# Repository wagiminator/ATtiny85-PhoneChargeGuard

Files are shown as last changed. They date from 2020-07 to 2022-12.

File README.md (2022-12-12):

# USB Phone Charge Guard
The ATtiny45/85 USB Phone Charge Guard controls and monitors the charging of phones and other devices. Voltage, current, power and energy are constantly measured via the INA219 and compared with the user limit values. It cuts off the power supply via a MOSFET when a condition selected by the user is reached. This allows the state of charge of the phone's Li-Ion battery to be controlled, thereby extending its service life. The user settings are saved in the EEPROM.

- Project Video (YouTube): https://youtu.be/9DHBoqHImcM
- Design Files (EasyEDA): https://easyeda.com/wagiminator/attiny85-phone-charge-guard

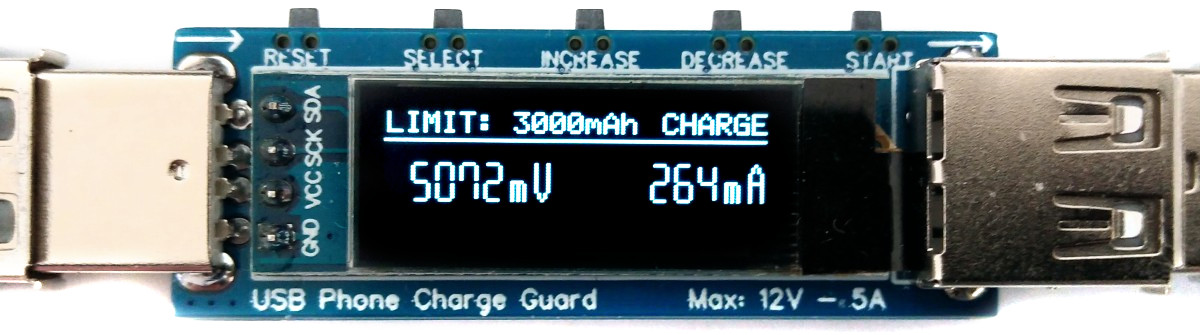
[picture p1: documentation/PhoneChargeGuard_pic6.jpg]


# Hardware
## USB Connectors
The device is equipped with a USB-A plug for the input and a USB-A socket for the output, so that it can be plugged between the power supply and the phone (or other consumers). D+ and D- are passed through so that the phone can negotiate the charging protocol.

## Voltage and Current Measurement
An [INA219](https://www.ti.com/lit/ds/symlink/ina219.pdf) is used to measure voltage and current. The INA219 is a current shunt and power monitor with an I²C-compatible interface. The device monitors both shunt voltage drop and bus supply voltage, with programmable conversion times and filtering. A programmable calibration value, combined with an internal multiplier, enables direct readouts of current in amperes. The selected shunt resistance of 8mΩ enables both a very small influence on the circuit and a measurement with a resolution of 1mA. For an accurate measurement, a shunt resistor with a low tolerance (1% or better) should be selected.

## Voltage Regulator
The device is supplied with 3.3V via an [HT7333](http://www.angeladvance.com/HT73xx.pdf) LDO voltage regulator, which taps the input voltage of up to 12V from the USB bus power.

## MOSFET
The connection between the power supply and the phone is switched on and off via an [AS3621](https://datasheet.lcsc.com/szlcsc/1809211432_AnBon-AS3621_C232288.pdf) P-channel MOSFET. Despite its small size, it can switch up to 30V with 6A continuously. Its internal on-resistance is only about 20 milliohms.

## User Interface
The user interface utilizes five buttons and an [SSD1306 128x32 pixels OLED display](http://aliexpress.com/wholesale?SearchText=128+32+0.91+oled). An [ATtiny45/85](https://ww1.microchip.com/downloads/en/DeviceDoc/Atmel-2586-AVR-8-bit-Microcontroller-ATtiny25-ATtiny45-ATtiny85_Datasheet.pdf) microcontroller handles the user interface, the control of the power connection and the calculation and display of the measured values.

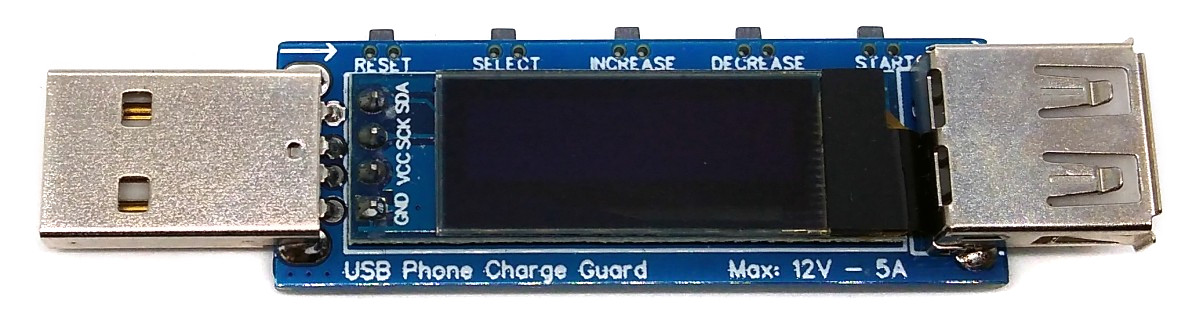
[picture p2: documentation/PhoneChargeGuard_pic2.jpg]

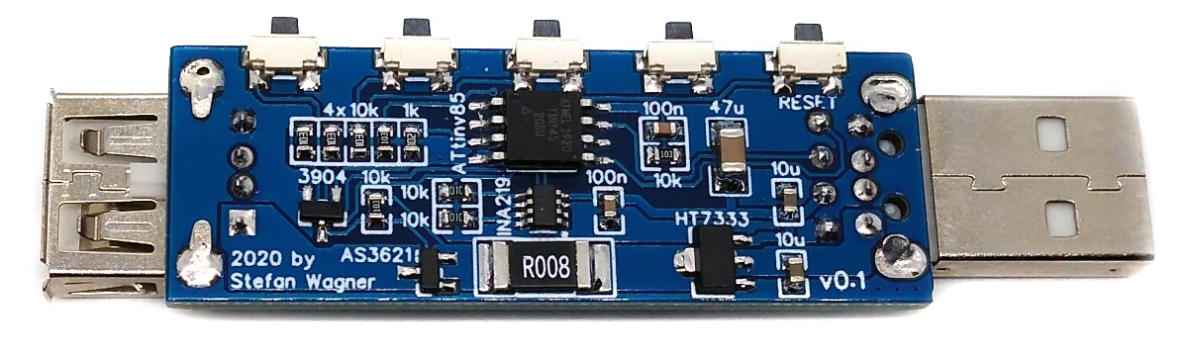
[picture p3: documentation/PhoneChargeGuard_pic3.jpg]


# Software
## Basic Principle
The INA219 continuously measures current and voltage and transmits the values to the ATtiny via I²C. From this, the ATtiny calculates the other values and displays them on the OLED screen. It controls the connection between the power supply and the phone via the MOSFET depending on the settings chosen by the user. The user settings are saved in the EEPROM and automatically loaded the next time it is used.

## I²C OLED Implementation
The I²C protocol implementation is based on a crude bitbanging method. It was specifically designed for the limited resources of ATtiny10 and ATtiny13, but it works with some other AVRs (including the ATtiny45/85) as well. The functions for the OLED are adapted to the SSD1306 OLED module, but they can easily be modified to be used for other modules. In order to save resources, only the basic functionalities which are needed for this application are implemented. For a detailed information on the working principle of the I²C OLED implementation visit [TinyOLEDdemo](https://github.com/wagiminator/attiny13-tinyoleddemo).

## Accuracy of Time and Capacity Determination
The internal oscillator of the ATtiny is used to determine energy and capacity. The accuracy of the internal oscillator is +/-10% with the factory calibration. This can be improved to +/-2% or better by [manual calibration](https://github.com/wagiminator/ATtiny84-TinyCalibrator). The calibration value determined in this way can be set in the source code.

## Compiling and Uploading
Since there is no ICSP header on the board, you have to program the ATtiny either before soldering using an [SOP adapter](https://aliexpress.com/wholesale?SearchText=sop-8+150mil+adapter), or after soldering using an [EEPROM clip](https://aliexpress.com/wholesale?SearchText=sop8+eeprom+programming+clip). The [AVR Programmer Adapter](https://github.com/wagiminator/AVR-Programmer/tree/master/AVR_Programmer_Adapter) can help with this.

### If using the Arduino IDE
- Make sure you have installed [ATtinyCore](https://github.com/SpenceKonde/ATTinyCore).
- Go to **Tools -> Board -> ATtinyCore** and select **ATtiny25/45/85 (No bootloader)**.
- Go to **Tools** and choose the following board options:
  - **Chip:**           ATtiny45 or 85 (depending on your chip)
  - **Clock:**          1 MHz (internal)
  - **B.O.D.Level:**    B.O.D. enabled (2.7V)
  - Leave the rest at the default settings
- Connect your programmer to your PC and to the ATtiny.
- Go to **Tools -> Programmer** and select your ISP programmer (e.g. [USBasp](https://aliexpress.com/wholesale?SearchText=usbasp)).
- Go to **Tools -> Burn Bootloader** to burn the fuses.
- Open the PhonChargeGuard sketch and click **Upload**.

### If using the precompiled hex-file
- Make sure you have installed [avrdude](https://learn.adafruit.com/usbtinyisp/avrdude).
- Connect your programmer to your PC and to the ATtiny.
- Open a terminal.
- Navigate to the folder with the hex-file.
- Execute the following command (if necessary replace "usbasp" with the programmer you use):
  ```
  avrdude -c usbasp -p t85 -U lfuse:w:0x62:m -U hfuse:w:0xd5:m -U efuse:w:0xff:m -U flash:w:phonechargeguard.hex
  ```

### If using the makefile (Linux/Mac)
- Make sure you have installed [avr-gcc toolchain and avrdude](http://maxembedded.com/2015/06/setting-up-avr-gcc-toolchain-on-linux-and-mac-os-x/).
- Connect your programmer to your PC and to the ATtiny.
- Open a terminal.
- Navigate to the folder with the makefile and the Arduino sketch.
- Run `DEVICE=attiny85 PROGRMR=usbasp make install` to compile, burn the fuses and upload the firmware (change DEVICE and PROGRMR accordingly).

# Operating Instructions
1. Connect the device between a power supply and the phone (or other consumer).
2. Use the SELECT/INCREASE/DECREASE buttons to set the charging limit.
3. Use the START button to start the charging process.
4. Use the SELECT button during charging to switch between the displayed values.
5. The charging process stops automatically when the set limit value is reached.

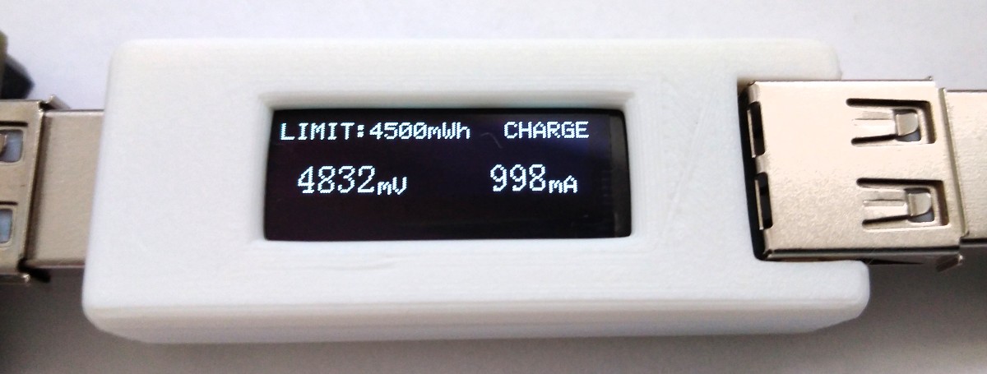
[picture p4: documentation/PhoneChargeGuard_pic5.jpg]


## Button Functions
|Button|Function|
|-|-|
|RESET|Reset all values|
|SELECT|Select limit type in pause mode / change displayed parameter in charging mode|
|INCREASE|Increase limit value|
|DECREASE|Decrease limit value|
|START|Start/pause charging|

## Selectable Charging Limits
|Limit Type|Function|
|-|-|
|mAh|Stop charging when electric charge reaches the selected value|
|mWh|Stop charging when provided energy reaches the selected value|
|mA|Stop charging when current falls below the selected value (this usually correlates with the state of charge of the battery)|
|min|Stop charging after the selected time in minutes|

## Characteristics
|Parameter|Value|
|-|-|
|Voltage|3V - 12V|
|Current|max 5A|
|Voltage Measurement Resolution|4mV|
|Current Measurement Resolution|1mA|

# References, Links and Notes
1. [ATtiny45/85 Datasheet](https://ww1.microchip.com/downloads/en/DeviceDoc/Atmel-2586-AVR-8-bit-Microcontroller-ATtiny25-ATtiny45-ATtiny85_Datasheet.pdf)
2. [INA219 Datasheet](https://www.ti.com/lit/ds/symlink/ina219.pdf)
3. [SSD1306 Datasheet](https://cdn-shop.adafruit.com/datasheets/SSD1306.pdf)
4. [HT7333 Datasheet](http://www.angeladvance.com/HT73xx.pdf)
5. [AS3621 Datasheet](https://datasheet.lcsc.com/szlcsc/1809211432_AnBon-AS3621_C232288.pdf)
6. [128x32 OLED on Aliexpress](http://aliexpress.com/wholesale?SearchText=128+32+0.91+oled)

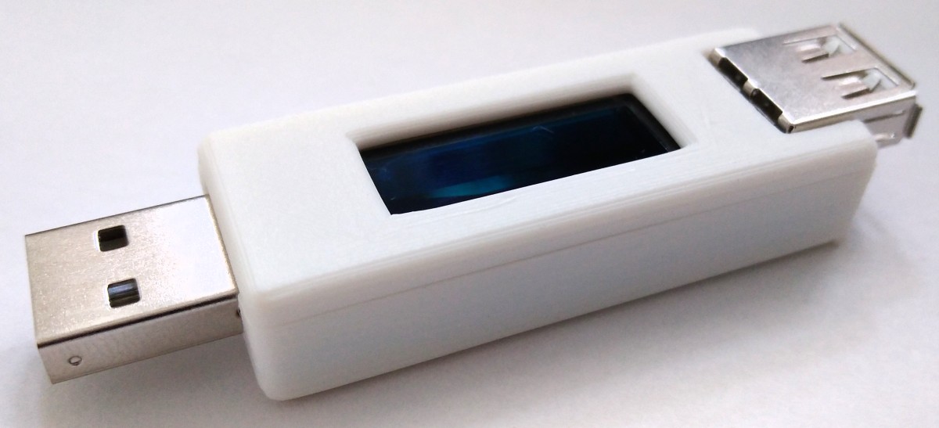
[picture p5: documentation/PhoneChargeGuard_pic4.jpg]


# License


This work is licensed under Creative Commons Attribution-ShareAlike 3.0 Unported License. 
(http://creativecommons.org/licenses/by-sa/3.0/)

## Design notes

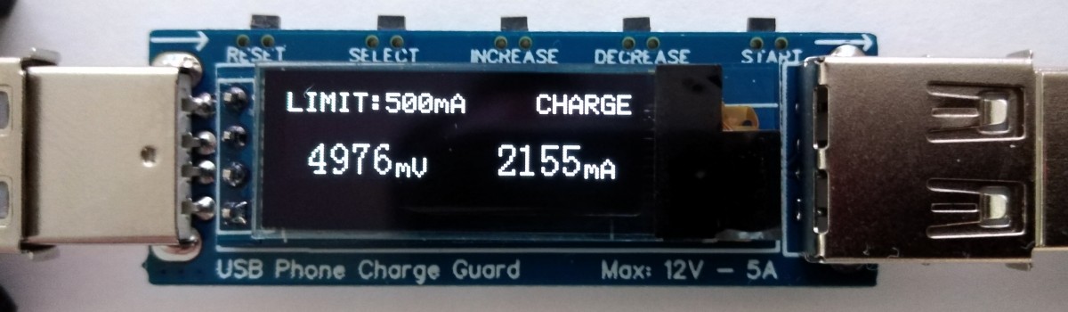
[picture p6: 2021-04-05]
documentation/PhoneChargeGuard_pic1.jpg

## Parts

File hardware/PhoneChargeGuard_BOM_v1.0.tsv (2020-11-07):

ID | Name | Designator | Footprint | Quantity | Manufacturer Part | Manufacturer | Supplier | Supplier Part | LCSC Assembly
1 | MMBT3904 | Q2 | SOT-23_1 | 1 | 2n3904S-RTK/PS | KEC | LCSC | C18536
2 | OLED 0.91 | OLED1 | I2C OLED 0.91 | 1 | SSD1306 I2C OLED
3 | POWER OUT | USB2 | USB-2.0-A-F-90-JCJ-H9.36 | 1 | USB-A-F-90 | LCSC | LCSC | C168708
4 | POWER IN | USB1 | USB-M-48 | 1 | USB-05 | SOFNG | LCSC | C112454
5 | TS24CA | SET4,SET3,SET2,RESET,SET1 | SW-SMD_TS24CA | 5 | TS24CA | SHOU HAN | LCSC | C393942
6 | 10k | R7,R4,R1,R10,R3,R9,R8,R5 | 0603 | 8 | 0603WAF1002T5E | UniOhm | LCSC | C25804
7 | 1k | R6 | 0603 | 1 | 0603WAF1001T5E | UniOhm | LCSC | C21190
8 | ATtiny85 | U1 | SOIC-8_208MIL | 1 | ATTINY85-20SU | MICROCHIP | LCSC | C89852
9 | HT7333-A | U3 | SOT-89-3_L4.5-W2.5-P1.50-LS4.2-BR | 1 | HT7333-A | HOLTEK | LCSC | C21583 | Yes
10 | INA219 | U2 | SOT-23-8_L3.0-W1.7-P0.65-LS2.8-BL | 1 | INA219AIDCNR | TI | LCSC | C87469 | Yes
11 | 100n | C1,C3 | 0603 | 2 | CC0603KRX7R9BB104 | YAGEO | LCSC | C14663
12 | 10u | C4,C5 | 0603 | 2 | CL10A106MA8NRNC | SAMSUNG | LCSC | C96446
13 | 47u | C2 | 1206 | 1 | CL31A476MQHNNNE | SAMSUNG | LCSC | C68361
14 | AS3621 | Q1 | SOT-23-3_L2.9-W1.3-P1.90-LS2.4-BR | 1 | AS3621 | AnBon | LCSC | C232288 | Yes
15 | R008 | R2 | 2512 | 1 | LCSR2512FR008Q9L | Resistor.Today | LCSC | C520396

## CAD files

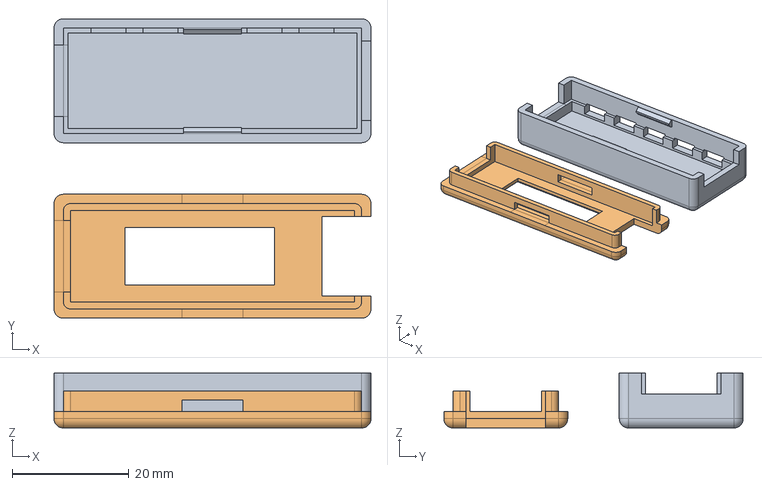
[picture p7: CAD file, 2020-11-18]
3dprint/PhoneChargeGuard_case.fcstd
54.2 x 51.2 x 9.40 mm
case_bottom
case_top

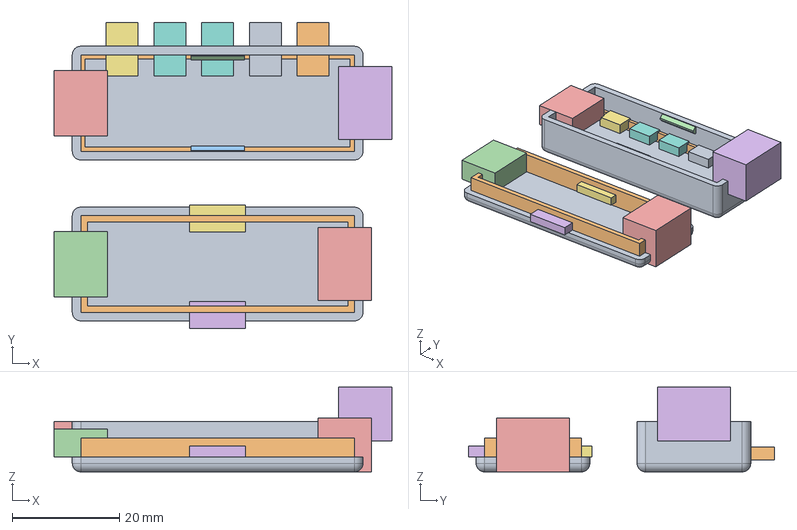
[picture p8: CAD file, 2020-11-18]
3dprint/PhoneChargeGuard_case_raw.fcstd
63.0 x 57.0 x 15.8 mm
Schale_unten
Auflage
Haken1
Haken2
USB_Stecker
USB_Buchse
Button1
Button2
Schale_oben
Rahmen
OLED
USB_Stecker2
USB_Buchse2
Oese1
Oese2
Button3
Button4
Button5

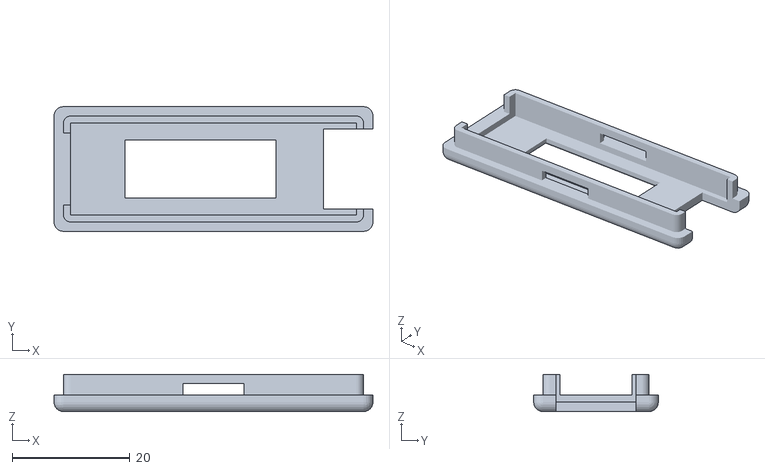
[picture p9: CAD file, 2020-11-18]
3dprint/PhoneChargeGuard_case_top.stl
54.2 x 21.2 x 6.30

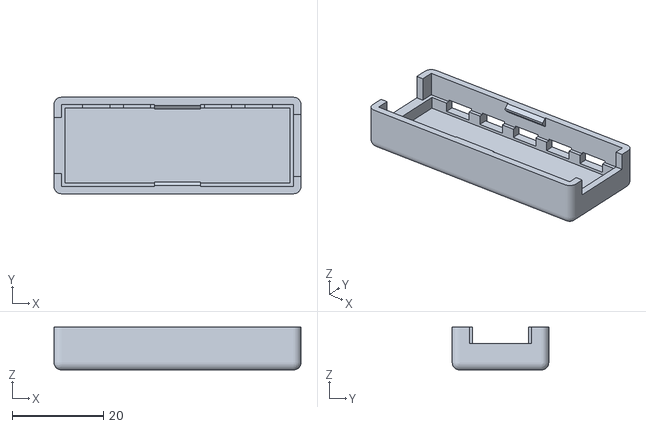
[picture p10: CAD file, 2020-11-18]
3dprint/PhoneChargeGuard_case_bottom.stl
54.2 x 21.2 x 9.40

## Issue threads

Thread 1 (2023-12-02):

How exactly are these fonts made?

parthbhat13, 2023-12-02:
Hi,
im so sorry to create a issue, i could not find any direct way to contact you. ive been a big fan of your projects and mainly how you play with the OLED displays and optimize the code. i was trying to use some fonts of yours in my code, but i saw that you have mostly stripped down a lot of things to save the memory. My most favouraite have been the 7 Segment style font. now i was wanting to use some letters like "I" , "A" or even in the big font. but i am so confused on how exactly have you made those fonts that i just was forced to contact you here as an issue. again sorry for that. but can you guide me how can i actually make more alphabets of the following fonts from your different codes.

```
// OLED 6x16 font
const uint8_t OLED_FONT_BIG[] = {
  0x7C, 0x1F, 0x02, 0x20, 0x02, 0x20, 0x02, 0x20, 0x02, 0x20, 0x7C, 0x1F, //  0 0
  0x00, 0x00, 0x00, 0x00, 0x00, 0x00, 0x00, 0x00, 0x00, 0x00, 0x7C, 0x1F, //  1 1
  0x00, 0x1F, 0x82, 0x20, 0x82, 0x20, 0x82, 0x20, 0x82, 0x20, 0x7C, 0x00, //  2 2
  0x00, 0x00, 0x82, 0x20, 0x82, 0x20, 0x82, 0x20, 0x82, 0x20, 0x7C, 0x1F, //  3 3
  0x7C, 0x00, 0x80, 0x00, 0x80, 0x00, 0x80, 0x00, 0x80, 0x00, 0x7C, 0x1F, //  4 4
  0x7C, 0x00, 0x82, 0x20, 0x82, 0x20, 0x82, 0x20, 0x82, 0x20, 0x00, 0x1F, //  5 5
  0x7C, 0x1F, 0x82, 0x20, 0x82, 0x20, 0x82, 0x20, 0x82, 0x20, 0x00, 0x1F, //  6 6
  0x7C, 0x00, 0x02, 0x00, 0x02, 0x00, 0x02, 0x00, 0x02, 0x00, 0x7C, 0x1F, //  7 7
  0x7C, 0x1F, 0x82, 0x20, 0x82, 0x20, 0x82, 0x20, 0x82, 0x20, 0x7C, 0x1F, //  8 8
  0x7C, 0x00, 0x82, 0x20, 0x82, 0x20, 0x82, 0x20, 0x82, 0x20, 0x7C, 0x1F, //  9 9
  0x00, 0x00, 0xF0, 0x3F, 0x8C, 0x00, 0x82, 0x00, 0x8C, 0x00, 0xF0, 0x3F, // 10 A
  0x00, 0x00, 0xFE, 0x07, 0x00, 0x18, 0x00, 0x20, 0x00, 0x18, 0xFE, 0x07, // 11 V
  0x00, 0x00, 0xFE, 0x1F, 0x00, 0x20, 0x00, 0x1F, 0x00, 0x20, 0xFE, 0x1F, // 12 W
  0x00, 0x00, 0xFE, 0x3F, 0x00, 0x01, 0x80, 0x00, 0x80, 0x00, 0x00, 0x3F, // 13 h
  0x00, 0x00, 0x80, 0x3F, 0x80, 0x00, 0x80, 0x3F, 0x80, 0x00, 0x00, 0x3F, // 14 m
  0x00, 0x00, 0x00, 0x00, 0x30, 0x06, 0x30, 0x06, 0x00, 0x00, 0x00, 0x00, // 15 :
  0x00, 0x00, 0x00, 0x00, 0x00, 0x00, 0x00, 0x00, 0x00, 0x00, 0x00, 0x00,  // 16 SPACE
};
```

another one is for the 7 segment style
```
// OLED 5x16 font 7 Segment
const uint8_t OLED_FONT[] = {
  0x7C, 0x1F, 0x02, 0x20, 0x02, 0x20, 0x02, 0x20, 0x7C, 0x1F, // 0  0
  0x00, 0x00, 0x00, 0x00, 0x00, 0x00, 0x00, 0x00, 0x7C, 0x1F, // 1  1
  0x00, 0x1F, 0x82, 0x20, 0x82, 0x20, 0x82, 0x20, 0x7C, 0x00, // 2  2
  0x00, 0x00, 0x82, 0x20, 0x82, 0x20, 0x82, 0x20, 0x7C, 0x1F, // 3  3
  0x7C, 0x00, 0x80, 0x00, 0x80, 0x00, 0x80, 0x00, 0x7C, 0x1F, // 4  4
  0x7C, 0x00, 0x82, 0x20, 0x82, 0x20, 0x82, 0x20, 0x00, 0x1F, // 5  5
  0x7C, 0x1F, 0x82, 0x20, 0x82, 0x20, 0x82, 0x20, 0x00, 0x1F, // 6  6
  0x0C, 0x00, 0x02, 0x00, 0x02, 0x00, 0x02, 0x00, 0x7C, 0x1F, // 7  7
  0x7C, 0x1F, 0x82, 0x20, 0x82, 0x20, 0x82, 0x20, 0x7C, 0x1F, // 8  8
  0x7C, 0x00, 0x82, 0x20, 0x82, 0x20, 0x82, 0x20, 0x7C, 0x1F, // 9  9
  0xF0, 0x3F, 0x8C, 0x00, 0x82, 0x00, 0x8C, 0x00, 0xF0, 0x3F, // A 10
  0xFE, 0x07, 0x00, 0x18, 0x00, 0x20, 0x00, 0x18, 0xFE, 0x07, // V 11
  0x00, 0x00, 0x30, 0x06, 0x30, 0x06, 0x00, 0x00, 0x00, 0x00, // : 12
  0x00, 0x00, 0x00, 0x00, 0x00, 0x00, 0x00, 0x00, 0x00, 0x00, //   13
  0x02, 0x00, 0x02, 0x00, 0x7E, 0x3F, 0x02, 0x00, 0x02, 0x00, // T 14
};
```

can you please give some guidance? or am i totally missing something?
as well these fonts are taking from different projects of yours, im trying to implement this on STM32G030F6P6TR, i do have memory restrictions too.  heres the C code attached.

```
/*
 * SSD1306.c
 *
 *  Created on: Dec 2, 2023
 *      Author: parthasus
 */

#include "stm32g0xx_hal.h"
#include "SSD1306.h"

// extern the i2c handler
extern I2C_HandleTypeDef hi2c2;
#define pgm_read_byte(addr) (*(const unsigned char *)(addr))

// Oled definitions
#define OLED_CMD_MODE   0x00    // set command mode
#define OLED_DAT_MODE   0x40    // set data mode
#define OLED_INIT_LEN   11      // 9: no screen flip, 11: screen flip

// OLED init settings
const uint8_t OLED_INIT_CMD[] = {
  0xA8, 0x1F,                   // set multiplex for 128x32
  0x20, 0x01,                   // set vertical memory addressing mode
  0xDA, 0x02,                   // set COM pins hardware configuration to sequential
  0x8D, 0x14,                   // enable charge pump
  0xAF,                         // switch on OLED
  0xA1, 0xC8                    // flip the screen
};

// OLED current page
uint8_t OLED_page;

// OLED 5x8 font (adapted from Neven Boyanov and Stephen Denne)
const uint8_t OLED_FONT_SMALL[]  = {
  0x3E, 0x51, 0x49, 0x45, 0x3E, //  0 0
  0x00, 0x42, 0x7F, 0x40, 0x00, //  1 1
  0x42, 0x61, 0x51, 0x49, 0x46, //  2 2
  0x21, 0x41, 0x45, 0x4B, 0x31, //  3 3
  0x18, 0x14, 0x12, 0x7F, 0x10, //  4 4
  0x27, 0x45, 0x45, 0x45, 0x39, //  5 5
  0x3C, 0x4A, 0x49, 0x49, 0x30, //  6 6
  0x01, 0x71, 0x09, 0x05, 0x03, //  7 7
  0x36, 0x49, 0x49, 0x49, 0x36, //  8 8
  0x06, 0x49, 0x49, 0x29, 0x1E, //  9 9
  0x7C, 0x12, 0x11, 0x12, 0x7C, // 10 A
  0x1F, 0x20, 0x40, 0x20, 0x1F, // 11 V
  0x3F, 0x40, 0x38, 0x40, 0x3F, // 12 W
  0x7F, 0x08, 0x04, 0x04, 0x78, // 13 h
  0x7C, 0x04, 0x18, 0x04, 0x78, // 14 m
  0x00, 0x36, 0x36, 0x00, 0x00, // 15 :
  0x00, 0x00, 0x00, 0x00, 0x00, // 16 SPACE
  0x3E, 0x41, 0x41, 0x41, 0x22, // 17 C
  0x7F, 0x49, 0x49, 0x49, 0x41, // 18 E
  0x3E, 0x41, 0x49, 0x49, 0x7A, // 19 G
  0x7F, 0x08, 0x08, 0x08, 0x7F, // 20 H
  0x00, 0x41, 0x7F, 0x41, 0x00, // 21 I
  0x7F, 0x40, 0x40, 0x40, 0x40, // 22 L
  0x7F, 0x02, 0x0C, 0x02, 0x7F, // 23 M
  0x7F, 0x09, 0x09, 0x09, 0x06, // 24 P
  0x7F, 0x09, 0x19, 0x29, 0x46, // 25 R
  0x46, 0x49, 0x49, 0x49, 0x31, // 26 S
  0x01, 0x01, 0x7F, 0x01, 0x01, // 27 T
  0x3F, 0x40, 0x40, 0x40, 0x3F, // 28 U
  0x00, 0x44, 0x7D, 0x40, 0x00, // 29 i
  0x7C, 0x08, 0x04, 0x04, 0x78,  // 30 n
  0x7F, 0x41, 0x41, 0x22, 0x1C, // D 31
  0x00, 0x60, 0x60, 0x00, 0x00, // . 32
};
// OLED 6x16 font
const uint8_t OLED_FONT_BIG[] = {
  0x7C, 0x1F, 0x02, 0x20, 0x02, 0x20, 0x02, 0x20, 0x02, 0x20, 0x7C, 0x1F, //  0 0
  0x00, 0x00, 0x00, 0x00, 0x00, 0x00, 0x00, 0x00, 0x00, 0x00, 0x7C, 0x1F, //  1 1
  0x00, 0x1F, 0x82, 0x20, 0x82, 0x20, 0x82, 0x20, 0x82, 0x20, 0x7C, 0x00, //  2 2
  0x00, 0x00, 0x82, 0x20, 0x82, 0x20, 0x82, 0x20, 0x82, 0x20, 0x7C, 0x1F, //  3 3
  0x7C, 0x00, 0x80, 0x00, 0x80, 0x00, 0x80, 0x00, 0x80, 0x00, 0x7C, 0x1F, //  4 4
  0x7C, 0x00, 0x82, 0x20, 0x82, 0x20, 0x82, 0x20, 0x82, 0x20, 0x00, 0x1F, //  5 5
  0x7C, 0x1F, 0x82, 0x20, 0x82, 0x20, 0x82, 0x20, 0x82, 0x20, 0x00, 0x1F, //  6 6
  0x7C, 0x00, 0x02, 0x00, 0x02, 0x00, 0x02, 0x00, 0x02, 0x00, 0x7C, 0x1F, //  7 7
  0x7C, 0x1F, 0x82, 0x20, 0x82, 0x20, 0x82, 0x20, 0x82, 0x20, 0x7C, 0x1F, //  8 8
  0x7C, 0x00, 0x82, 0x20, 0x82, 0x20, 0x82, 0x20, 0x82, 0x20, 0x7C, 0x1F, //  9 9
  0x00, 0x00, 0xF0, 0x3F, 0x8C, 0x00, 0x82, 0x00, 0x8C, 0x00, 0xF0, 0x3F, // 10 A
  0x00, 0x00, 0xFE, 0x07, 0x00, 0x18, 0x00, 0x20, 0x00, 0x18, 0xFE, 0x07, // 11 V
  0x00, 0x00, 0xFE, 0x1F, 0x00, 0x20, 0x00, 0x1F, 0x00, 0x20, 0xFE, 0x1F, // 12 W
  0x00, 0x00, 0xFE, 0x3F, 0x00, 0x01, 0x80, 0x00, 0x80, 0x00, 0x00, 0x3F, // 13 h
  0x00, 0x00, 0x80, 0x3F, 0x80, 0x00, 0x80, 0x3F, 0x80, 0x00, 0x00, 0x3F, // 14 m
  0x00, 0x00, 0x00, 0x00, 0x30, 0x06, 0x30, 0x06, 0x00, 0x00, 0x00, 0x00, // 15 :
  0x00, 0x00, 0x00, 0x00, 0x00, 0x00, 0x00, 0x00, 0x00, 0x00, 0x00, 0x00,  // 16 SPACE

};

// OLED 5x16 font 7 Segment
const uint8_t OLED_FONT[] = {
  0x7C, 0x1F, 0x02, 0x20, 0x02, 0x20, 0x02, 0x20, 0x7C, 0x1F, // 0  0
  0x00, 0x00, 0x00, 0x00, 0x00, 0x00, 0x00, 0x00, 0x7C, 0x1F, // 1  1
  0x00, 0x1F, 0x82, 0x20, 0x82, 0x20, 0x82, 0x20, 0x7C, 0x00, // 2  2
  0x00, 0x00, 0x82, 0x20, 0x82, 0x20, 0x82, 0x20, 0x7C, 0x1F, // 3  3
  0x7C, 0x00, 0x80, 0x00, 0x80, 0x00, 0x80, 0x00, 0x7C, 0x1F, // 4  4
  0x7C, 0x00, 0x82, 0x20, 0x82, 0x20, 0x82, 0x20, 0x00, 0x1F, // 5  5
  0x7C, 0x1F, 0x82, 0x20, 0x82, 0x20, 0x82, 0x20, 0x00, 0x1F, // 6  6
  0x0C, 0x00, 0x02, 0x00, 0x02, 0x00, 0x02, 0x00, 0x7C, 0x1F, // 7  7
  0x7C, 0x1F, 0x82, 0x20, 0x82, 0x20, 0x82, 0x20, 0x7C, 0x1F, // 8  8
  0x7C, 0x00, 0x82, 0x20, 0x82, 0x20, 0x82, 0x20, 0x7C, 0x1F, // 9  9
  0xF0, 0x3F, 0x8C, 0x00, 0x82, 0x00, 0x8C, 0x00, 0xF0, 0x3F, // A 10
  0xFE, 0x07, 0x00, 0x18, 0x00, 0x20, 0x00, 0x18, 0xFE, 0x07, // V 11
  0x00, 0x00, 0x30, 0x06, 0x30, 0x06, 0x00, 0x00, 0x00, 0x00, // : 12
  0x00, 0x00, 0x00, 0x00, 0x00, 0x00, 0x00, 0x00, 0x00, 0x00, //   13
  0x02, 0x00, 0x02, 0x00, 0x7E, 0x3F, 0x02, 0x00, 0x02, 0x00, // T 14
};

// Internal Function Prototype
void i2cWrite(uint8_t oledAddr, uint8_t oledReg, uint8_t oledData);

// global functions
uint8_t dispInit()
{
	if(HAL_I2C_IsDeviceReady(&hi2c2, OLED_ADDR, 2, 2000) != HAL_OK)
	{
		return 0;
	}

	for(uint8_t i = 0; i < OLED_INIT_LEN; i++)
	{
		i2cWrite(OLED_ADDR, OLED_CMD_MODE, OLED_INIT_CMD[i]);
	}

	return 1;
}

void dispSetCursor(uint8_t xPos, uint8_t yPos)
{
	i2cWrite(OLED_ADDR, OLED_CMD_MODE, 0x22);
	i2cWrite(OLED_ADDR, OLED_CMD_MODE, yPos);

	(yPos > 1) ? (i2cWrite(OLED_ADDR, OLED_CMD_MODE, 3)) : (i2cWrite(OLED_ADDR, OLED_CMD_MODE, yPos));

	i2cWrite(OLED_ADDR, OLED_CMD_MODE, xPos & 0x0F);
	i2cWrite(OLED_ADDR, OLED_CMD_MODE, 0x10 | (xPos >> 4));
	i2cWrite(OLED_ADDR, OLED_CMD_MODE, 0xB0 | (yPos));
	OLED_page = yPos;
}

void dispClearScreen(void)
{
	uint8_t i;
	dispSetCursor(0, 0);
	for(i = OLED_WIDTH; i; i--) i2cWrite(OLED_ADDR, OLED_DAT_MODE, 0x00);

	dispSetCursor(0, 1);
	for(i = OLED_WIDTH; i; i--) i2cWrite(OLED_ADDR, OLED_DAT_MODE, 0x02);

	dispSetCursor(0, 2);
	do { i2cWrite(OLED_ADDR, OLED_DAT_MODE, 0x00); } while (--i);
}

void dispPlotChar(uint8_t ch)
{
	if(OLED_page)
	{
		ch = (ch << 3) + (ch << 2);
		i2cWrite(OLED_ADDR, OLED_DAT_MODE, 0x00);
		i2cWrite(OLED_ADDR, OLED_DAT_MODE, 0x00);
		for(uint8_t i = 12; i; i--)
			i2cWrite(OLED_ADDR, OLED_DAT_MODE, pgm_read_byte(&OLED_FONT_BIG[ch++]));
		i2cWrite(OLED_ADDR, OLED_DAT_MODE, 0x00);
		i2cWrite(OLED_ADDR, OLED_DAT_MODE, 0x00);
	}
	else
	{
		ch += (ch << 2);
		i2cWrite(OLED_ADDR, OLED_DAT_MODE, 0x00);
		for(uint8_t i = 5; i; i--)
			i2cWrite(OLED_ADDR, OLED_DAT_MODE, pgm_read_byte(&OLED_FONT_SMALL[ch++]));
		//i2cWrite(OLED_ADDR, OLED_DAT_MODE, 0x00);
		//i2cWrite(OLED_ADDR, OLED_DAT_MODE, 0x00);
	}
}

void dispPlotSevenSegment(uint8_t xPos, uint8_t yPos, uint8_t ch)
{
	i2cWrite(OLED_ADDR, OLED_CMD_MODE, 0x22);
	i2cWrite(OLED_ADDR, OLED_CMD_MODE, yPos);

	(yPos > 1) ? (i2cWrite(OLED_ADDR, OLED_CMD_MODE, 3)) : (i2cWrite(OLED_ADDR, OLED_CMD_MODE, yPos));

	i2cWrite(OLED_ADDR, OLED_CMD_MODE, xPos & 0x0F);
	i2cWrite(OLED_ADDR, OLED_CMD_MODE, 0x10 | (xPos >> 4));
	i2cWrite(OLED_ADDR, OLED_CMD_MODE, 0xB0 | (yPos));

	ch = (ch << 1) + (ch << 3);
	i2cWrite(OLED_ADDR, OLED_DAT_MODE, 0x00);
	i2cWrite(OLED_ADDR, OLED_DAT_MODE, 0x00);
	for(uint8_t i = 10; i; i--)
		i2cWrite(OLED_ADDR, OLED_DAT_MODE, pgm_read_byte(&OLED_FONT[ch++]));
}

void dispPrintChar(uint8_t ch)
{
	dispPlotChar(ch);
}

void dispPrint(const uint8_t *p)
{
	uint8_t ch = pgm_read_byte(p);
	while(ch < 255)
	{
		dispPlotChar(ch);
		 ch = pgm_read_byte(++p);
	}
}

// internal functions
void i2cWrite(uint8_t oledAddr, uint8_t oledReg, uint8_t oledData)
{
	uint8_t data[2];
	data[0] = oledReg;
	data[1] = oledData;
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
wagiminator, 2023-12-02:
Hi, I actually drew these fonts in the old school way on graph paper and then calculated the individual bytes in my head. Of course you can use an OLED font editor, such as this one: https://sourpuss.net/projects/fontedit/

parthbhat13, 2023-12-04:
Hi,
Thanks for your response. I was running away from going deep into the whole oled and screen things but I guess I eventually have to haha.
Thanks for the website. I guess I better start from scratch and learn rather than to copy paste.

Thanks again.

wagiminator, 2023-12-09:
You can use the Arduino IDE. There are certainly a lot of ready-made libraries for different displays, many fonts to choose from and certainly tools for font creation.

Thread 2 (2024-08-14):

Any chance for a USB-PD version?

tomash, 2024-08-14:
As in the title: any chance for a version supporting USB-PD, with USB-C on both sides? The USB-PD charge still to be negotiated between both devices connected at the ends, I'd just like ChargeGuard to disconnect the VBUS when charging power (or current) drops below a certain threshold, just like in the USB-A version.

wagiminator, 2024-08-15:
That's definitely possible. I'll add it to my to-do list, which is already soooooooooooooooooo long....

tomash, 2024-08-20:
I'll start with doing a clone/fork on oshwlab. I designed and made a few devices, but I'm a hobbyist when it comes to hardware so at some point I will be asking for your feedback :sweat_smile:

wagiminator, 2024-08-24:
I wish you success!

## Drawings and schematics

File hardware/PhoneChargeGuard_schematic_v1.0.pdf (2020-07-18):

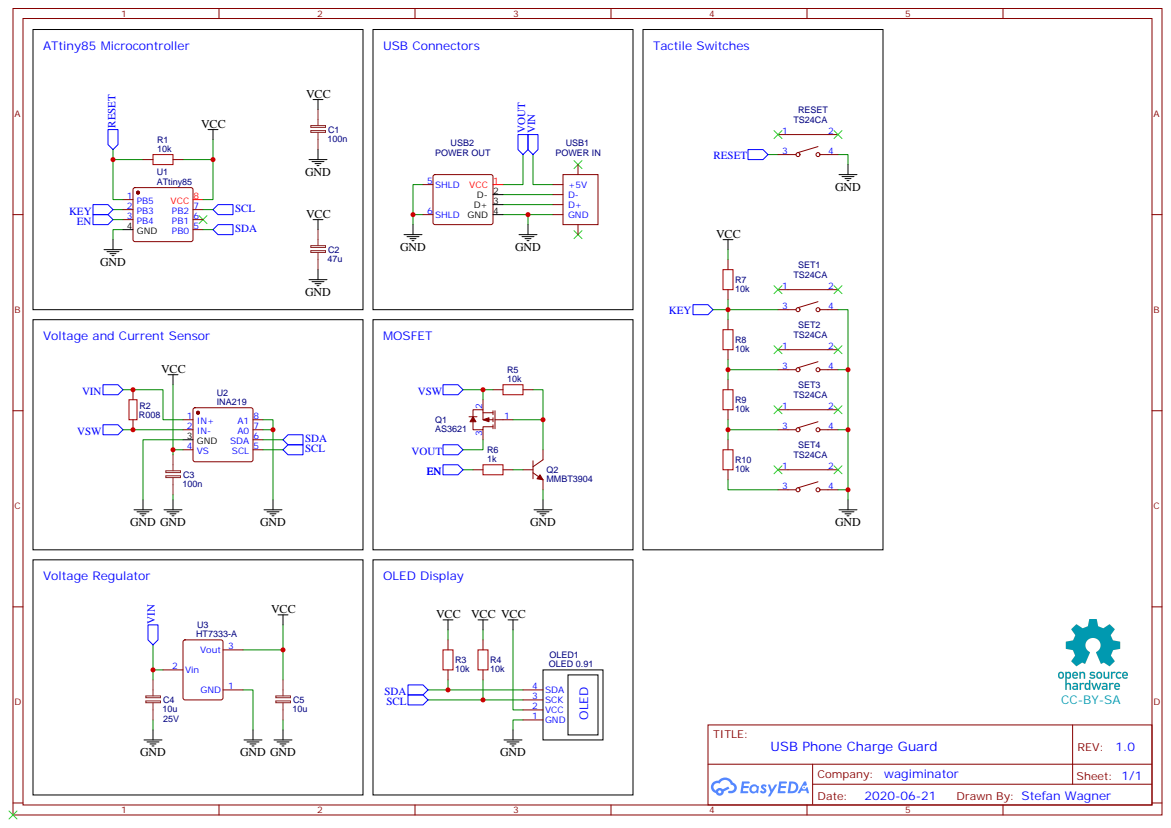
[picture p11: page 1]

Voltage and Current Sensor

Drawn By: Stefan Wagner

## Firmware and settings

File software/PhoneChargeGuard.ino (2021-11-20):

// ===================================================================================
// Project:   USB Phone Charge Guard based on ATtiny45/85
// Version:   v1.2
// Year:      2020 - 2021
// Author:    Stefan Wagner
// Github:    https://github.com/wagiminator
// EasyEDA:   https://easyeda.com/wagiminator
// License:   http://creativecommons.org/licenses/by-sa/3.0/
// ===================================================================================
//
// Description:
// ------------
// The ATtiny45/85 USB Phone Charge Guard controls and monitors the charging of
// phones and other devices. Voltage, current, power and energy are constantly
// measured via the INA219 and compared with the user limit values. It cuts off
// the power supply via a MOSFET when a condition selected by the user is reached.
// This allows the state of charge of the phone's Li-ion battery to be controlled,
// thereby extending its service life. The user settings are saved in the EEPROM.
//
// References:
// -----------
// The I²C OLED implementation is based on TinyOLEDdemo
// https://github.com/wagiminator/ATtiny13-TinyOLEDdemo
//
// Wiring:
// -------
//                            +-\/-+
//   RESET --- RST ADC0 PB5  1|°   |8  Vcc
// BUTTONS ------- ADC3 PB3  2|    |7  PB2 ADC1 -------- OLED/INA SCK
//  ENABLE ------- ADC2 PB4  3|    |6  PB1 AIN1 OC0B --- 
//                      GND  4|    |5  PB0 AIN0 OC0A --- OLED/INA SDA
//                            +----+
//
// Compilation Settings:
// ---------------------
// Core:    ATtinyCore (https://github.com/SpenceKonde/ATTinyCore)
// Board:   ATtiny25/45/85 (No bootloader)
// Chip:    ATtiny45 or ATtiny85 (depending on your chip)
// Clock:   1 MHz (internal)
// B.O.D.:  2.7V
//
// Leave the rest on default settings. Don't forget to "Burn bootloader"!
// No Arduino core functions or libraries are used. Use the makefile if 
// you want to compile without Arduino IDE.
//
// Note: The internal oscillator may need to be calibrated for precise
//       energy and capacity calculation.
//
// Fuse settings: -U lfuse:w:0x62:m -U hfuse:w:0xd5:m -U efuse:w:0xff:m 
//
// Operating Instructions:
// -----------------------
// Connect the device between a power supply and the phone (or other consumer).
// Use the SELECT/INCREASE/DECREASE buttons to set the charging limit.
// Use the START button to start the charging process.
// Use the SELECT button during charging to switch between the displayed values.
// The charging process stops automatically when the set limit value is reached.
//
// Buttons:
// RESET:     Reset all values
// SELECT:    Select limit type in pause mode/
//            change displayed parameter in charging mode
// INCREASE:  Increase limit value
// DECREASE:  Decrease limit value
// START:     Start/pause charging
//
// Limit types:
// mAh:       Stop charging when electric charge reaches the selected value
// mWh:       Stop charging when provided energy reaches the selected value
// mA:        Stop charging when current falls below the selected value
//            (this usually correlates with the state of charge of the battery)
// min:       Stop charging after the selected time in minutes


// ===================================================================================
// Libraries and Definitions
// ===================================================================================

// Oscillator calibration value (uncomment and set if necessary)
// #define OSCCAL_VAL  0x48

// Libraries
#include <avr/io.h>             // for GPIO
#include <avr/eeprom.h>         // for storing data in EEPROM
#include <avr/pgmspace.h>       // for data stored in program memory
#include <avr/interrupt.h>      // for interrupts
#include <util/delay.h>         // for delays

// Pin definitions
#define PIN_SDA     PB0         // I2C serial data pin, connected to OLED/INA219
#define PIN_SCL     PB2         // I2C serial clock pin, connected to OLED/INA219
#define PIN_KEYS    PB3         // pin connected to buttons array
#define PIN_ENABLE  PB4         // pin connected to MOSFET for power enable

// EEPROM identifier
#define EEPROM_IDENT   0xA76D   // to identify if EEPROM was written by this program

// Global variables
uint8_t   limit = 0;            // limit type selection flag
uint8_t   showValue = 0;        // displayed values selection flag

// Button enumeration
enum{ NO_KEY, KEY_SELECT, KEY_INC, KEY_DEC, KEY_START };

// Limits                               mAh    mWh    mA  min
uint16_t       limit_val[]         = { 3000, 15000,  200, 180};  // current value
const uint16_t limit_min[] PROGMEM = {  500,  1000,  100,  10};  // minimum value
const uint16_t limit_max[] PROGMEM = {10000, 50000, 3000, 590};  // maximum value
const uint16_t limit_inc[] PROGMEM = {  100,   500,  100,  10};  // inc/dec step

// Pin manipulation macros
#define pinInput(x)   DDRB  &= ~(1<<(x))    // set pin to INPUT
#define pinOutput(x)  DDRB  |=  (1<<(x))    // set pin to OUTPUT
#define pinLow(x)     PORTB &= ~(1<<(x))    // set pin to LOW
#define pinHigh(x)    PORTB |=  (1<<(x))    // set pin to HIGH
#define pinDisable(x) DIDR0 |=  (1<<(x))    // disable digital input buffer
#define pinRead(x)    (PINB &   (1<<(x)))   // READ pin
#define pinADC(x)     ((x)==2?1:((x)==3?3:((x)==4?2:0))) // convert pin to ADC port

// ===================================================================================
// I2C Master Implementation
// ===================================================================================

// I2C macros
#define I2C_SDA_HIGH()  pinInput(PIN_SDA)       // release SDA   -> pulled HIGH by resistor
#define I2C_SDA_LOW()   pinOutput(PIN_SDA)      // SDA as output -> pulled LOW  by MCU
#define I2C_SCL_HIGH()  pinInput(PIN_SCL)       // release SCL   -> pulled HIGH by resistor
#define I2C_SCL_LOW()   pinOutput(PIN_SCL)      // SCL as output -> pulled LOW  by MCU
#define I2C_SDA_READ()  pinRead(PIN_SDA)        // read SDA line
#define I2C_CLOCKOUT()  I2C_SCL_HIGH();I2C_SCL_LOW()  // clock out

// I2C transmit one data byte to the slave, ignore ACK bit, no clock stretching allowed
void I2C_write(uint8_t data) {
  for(uint8_t i=8; i; i--, data<<=1) {          // transmit 8 bits, MSB first
    (data&0x80)?I2C_SDA_HIGH():I2C_SDA_LOW();   // SDA depending on bit
    I2C_CLOCKOUT();                             // clock out -> slave reads the bit
  }
  I2C_SDA_HIGH();                               // release SDA for ACK bit of slave
  I2C_CLOCKOUT();                               // 9th clock pulse is for the ignored ACK bit
}

// I2C start transmission
void I2C_start(uint8_t addr) {
  I2C_SDA_LOW();                                // start condition: SDA goes LOW first
  I2C_SCL_LOW();                                // start condition: SCL goes LOW second
  I2C_write(addr);                              // send slave address
}

// I2C restart transmission
void I2C_restart(uint8_t addr) {
  I2C_SDA_HIGH();                               // prepare SDA for HIGH to LOW transition
  I2C_SCL_HIGH();                               // restart condition: clock HIGH
  I2C_start(addr);                              // start again
}

// I2C stop transmission
void I2C_stop(void) {
  I2C_SDA_LOW();                                // prepare SDA for LOW to HIGH transition
  I2C_SCL_HIGH();                               // stop condition: SCL goes HIGH first
  I2C_SDA_HIGH();                               // stop condition: SDA goes HIGH second
}

// I2C receive one data byte from the slave (ack=0 for last byte, ack>0 if more bytes to follow)
uint8_t I2C_read(uint8_t ack) {
  uint8_t data = 0;                             // variable for the received byte
  I2C_SDA_HIGH();                               // release SDA -> will be toggled by slave
  for(uint8_t i=8; i; i--) {                    // receive 8 bits
    data <<= 1;                                 // bits shifted in right (MSB first)
    I2C_SCL_HIGH();                             // clock HIGH
    if(I2C_SDA_READ()) data |= 1;               // read bit
    I2C_SCL_LOW();                              // clock LOW -> slave prepares next bit
  }
  if(ack) I2C_SDA_LOW();                        // pull SDA LOW to acknowledge (ACK)
  I2C_CLOCKOUT();                               // clock out -> slave reads ACK bit
  return data;                                  // return the received byte
}

// ===================================================================================
// OLED Implementation
// ===================================================================================

// OLED definitions
#define OLED_ADDR       0x78    // OLED write address
#define OLED_CMD_MODE   0x00    // set command mode
#define OLED_DAT_MODE   0x40    // set data mode
#define OLED_INIT_LEN   11      // 9: no screen flip, 11: screen flip

// OLED init settings
const uint8_t OLED_INIT_CMD[] PROGMEM = {
  0xA8, 0x1F,                   // set multiplex for 128x32
  0x20, 0x01,                   // set vertical memory addressing mode
  0xDA, 0x02,                   // set COM pins hardware configuration to sequential
  0x8D, 0x14,                   // enable charge pump
  0xAF,                         // switch on OLED
  0xA1, 0xC8                    // flip the screen
};

// OLED 5x8 font (adapted from Neven Boyanov and Stephen Denne)
const uint8_t OLED_FONT_SMALL[] PROGMEM = {
  0x3E, 0x51, 0x49, 0x45, 0x3E, //  0 0
  0x00, 0x42, 0x7F, 0x40, 0x00, //  1 1
  0x42, 0x61, 0x51, 0x49, 0x46, //  2 2
  0x21, 0x41, 0x45, 0x4B, 0x31, //  3 3
  0x18, 0x14, 0x12, 0x7F, 0x10, //  4 4
  0x27, 0x45, 0x45, 0x45, 0x39, //  5 5
  0x3C, 0x4A, 0x49, 0x49, 0x30, //  6 6
  0x01, 0x71, 0x09, 0x05, 0x03, //  7 7
  0x36, 0x49, 0x49, 0x49, 0x36, //  8 8
  0x06, 0x49, 0x49, 0x29, 0x1E, //  9 9
  0x7C, 0x12, 0x11, 0x12, 0x7C, // 10 A
  0x1F, 0x20, 0x40, 0x20, 0x1F, // 11 V
  0x3F, 0x40, 0x38, 0x40, 0x3F, // 12 W
  0x7F, 0x08, 0x04, 0x04, 0x78, // 13 h
  0x7C, 0x04, 0x18, 0x04, 0x78, // 14 m
  0x00, 0x36, 0x36, 0x00, 0x00, // 15 :
  0x00, 0x00, 0x00, 0x00, 0x00, // 16 SPACE
  0x3E, 0x41, 0x41, 0x41, 0x22, // 17 C
  0x7F, 0x49, 0x49, 0x49, 0x41, // 18 E
  0x3E, 0x41, 0x49, 0x49, 0x7A, // 19 G
  0x7F, 0x08, 0x08, 0x08, 0x7F, // 20 H
  0x00, 0x41, 0x7F, 0x41, 0x00, // 21 I
  0x7F, 0x40, 0x40, 0x40, 0x40, // 22 L
  0x7F, 0x02, 0x0C, 0x02, 0x7F, // 23 M
  0x7F, 0x09, 0x09, 0x09, 0x06, // 24 P
  0x7F, 0x09, 0x19, 0x29, 0x46, // 25 R
  0x46, 0x49, 0x49, 0x49, 0x31, // 26 S
  0x01, 0x01, 0x7F, 0x01, 0x01, // 27 T
  0x3F, 0x40, 0x40, 0x40, 0x3F, // 28 U
  0x00, 0x44, 0x7D, 0x40, 0x00, // 29 i
  0x7C, 0x08, 0x04, 0x04, 0x78  // 30 n
};

// OLED 6x16 font
const uint8_t OLED_FONT_BIG[] PROGMEM = {
  0x7C, 0x1F, 0x02, 0x20, 0x02, 0x20, 0x02, 0x20, 0x02, 0x20, 0x7C, 0x1F, //  0 0
  0x00, 0x00, 0x00, 0x00, 0x00, 0x00, 0x00, 0x00, 0x00, 0x00, 0x7C, 0x1F, //  1 1
  0x00, 0x1F, 0x82, 0x20, 0x82, 0x20, 0x82, 0x20, 0x82, 0x20, 0x7C, 0x00, //  2 2
  0x00, 0x00, 0x82, 0x20, 0x82, 0x20, 0x82, 0x20, 0x82, 0x20, 0x7C, 0x1F, //  3 3
  0x7C, 0x00, 0x80, 0x00, 0x80, 0x00, 0x80, 0x00, 0x80, 0x00, 0x7C, 0x1F, //  4 4
  0x7C, 0x00, 0x82, 0x20, 0x82, 0x20, 0x82, 0x20, 0x82, 0x20, 0x00, 0x1F, //  5 5
  0x7C, 0x1F, 0x82, 0x20, 0x82, 0x20, 0x82, 0x20, 0x82, 0x20, 0x00, 0x1F, //  6 6
  0x7C, 0x00, 0x02, 0x00, 0x02, 0x00, 0x02, 0x00, 0x02, 0x00, 0x7C, 0x1F, //  7 7
  0x7C, 0x1F, 0x82, 0x20, 0x82, 0x20, 0x82, 0x20, 0x82, 0x20, 0x7C, 0x1F, //  8 8
  0x7C, 0x00, 0x82, 0x20, 0x82, 0x20, 0x82, 0x20, 0x82, 0x20, 0x7C, 0x1F, //  9 9
  0x00, 0x00, 0xF0, 0x3F, 0x8C, 0x00, 0x82, 0x00, 0x8C, 0x00, 0xF0, 0x3F, // 10 A
  0x00, 0x00, 0xFE, 0x07, 0x00, 0x18, 0x00, 0x20, 0x00, 0x18, 0xFE, 0x07, // 11 V
  0x00, 0x00, 0xFE, 0x1F, 0x00, 0x20, 0x00, 0x1F, 0x00, 0x20, 0xFE, 0x1F, // 12 W
  0x00, 0x00, 0xFE, 0x3F, 0x00, 0x01, 0x80, 0x00, 0x80, 0x00, 0x00, 0x3F, // 13 h
  0x00, 0x00, 0x80, 0x3F, 0x80, 0x00, 0x80, 0x3F, 0x80, 0x00, 0x00, 0x3F, // 14 m
  0x00, 0x00, 0x00, 0x00, 0x30, 0x06, 0x30, 0x06, 0x00, 0x00, 0x00, 0x00, // 15 :
  0x00, 0x00, 0x00, 0x00, 0x00, 0x00, 0x00, 0x00, 0x00, 0x00, 0x00, 0x00  // 16 SPACE
};

// Character definitions
#define COLON   15
#define SPACE   16

// OLED BCD conversion array
const uint16_t DIVIDER[] PROGMEM = {10000, 1000, 100, 10, 1};

// OLED current page
uint8_t OLED_page;

// OLED init function
void OLED_init(void) {
  I2C_start(OLED_ADDR);                         // start transmission to OLED
  I2C_write(OLED_CMD_MODE);                     // set command mode
  for(uint8_t i=0; i<OLED_INIT_LEN; i++) 
    I2C_write(pgm_read_byte(&OLED_INIT_CMD[i]));// send the command bytes
  I2C_stop();                                   // stop transmission
}

// OLED set the cursor
void OLED_setCursor(uint8_t xpos, uint8_t ypos) {
  I2C_start(OLED_ADDR);                         // start transmission to OLED
  I2C_write(OLED_CMD_MODE);                     // set command mode
  I2C_write(0x22);                              // command for min/max page
  I2C_write(ypos);                              // min: ypos
  (ypos > 1) ? I2C_write(3) : I2C_write(ypos);  // max: depending
  I2C_write(xpos & 0x0F);                       // set low nibble of start column
  I2C_write(0x10 | (xpos >> 4));                // set high nibble of start column
  I2C_write(0xB0 | (ypos));                     // set start page
  I2C_stop();                                   // stop transmission
  OLED_page = ypos;
}

// OLED clear screen
void OLED_clearScreen(void) {
  uint8_t i;                                    // count variable
  OLED_setCursor(0, 0);                         // set cursor at line 0
  I2C_start(OLED_ADDR);                         // start transmission to OLED
  I2C_write(OLED_DAT_MODE);                     // set data mode
  for(i = 128; i; i--) I2C_write(0x00);         // clear line
  I2C_stop();                                   // stop transmission

  OLED_setCursor(0, 1);                         // set cursor at line 1
  I2C_start(OLED_ADDR);                         // start transmission to OLED
  I2C_write(OLED_DAT_MODE);                     // set data mode
  for(i = 128; i; i--) I2C_write(0x02);         // draw line
  I2C_stop();                                   // stop transmission

  OLED_setCursor(0, 2);                         // set cursor at lower half
  I2C_start(OLED_ADDR);                         // start transmission to OLED
  I2C_write(OLED_DAT_MODE);                     // set data mode
  do {I2C_write(0x00);} while(--i);             // clear lower half
  I2C_stop();                                   // stop transmission
}

// OLED plot a character
void OLED_plotChar(uint8_t ch) {
  if(OLED_page) {                               // big character ?
    ch = (ch << 3) + (ch << 2);                 // calculate position of character in font array
    I2C_write(0x00); I2C_write(0x00);           // print spacing between characters
    for(uint8_t i=12; i; i--)                   // 12 bytes per character
      I2C_write(pgm_read_byte(&OLED_FONT_BIG[ch++])); // print character
    I2C_write(0x00); I2C_write(0x00);           // print spacing between characters
  }
  else {                                        // small character ?
    ch += (ch << 2);                            // calculate position of character in font array
    I2C_write(0x00);                            // print spacing between characters
    for(uint8_t i=5; i; i--)                    // 5 bytes per character
      I2C_write(pgm_read_byte(&OLED_FONT_SMALL[ch++])); // print character
  }
}

// OLED print a character
void OLED_printChar(uint8_t ch) {
  I2C_start(OLED_ADDR);                         // start transmission to OLED
  I2C_write(OLED_DAT_MODE);                     // set data mode
  OLED_plotChar(ch);                            // plot the character
  I2C_stop();                                   // stop transmission
}
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
int main(void) {
  // Local variables
  uint16_t  voltage, current, power;            // voltage in mV, current in mA, power in mW
  uint32_t  lastmillis, nowmillis, interval;    // for timing calculation in millis
  uint32_t  limitmillis;                        // timer limit
  uint32_t  chargetime = 0;                     // total charge time in millis
  uint16_t  seconds, minutes;                   // total duration in seconds and minutes
  uint32_t  capacity = 0, energy = 0;           // counter for capacity in uAh and energy in uWh
  uint8_t   lastbutton  = 0;                    // button flag (0: button pressed)
  uint8_t   button;                             // button number
  uint8_t   isCharging = 0;                     // charging flag (0: not charging)

  // Set oscillator calibration value
  #ifdef OSCCAL_VAL
    OSCCAL = OSCCAL_VAL;                        // set the value if defined above
  #endif

  // Setup
  pinOutput(PIN_ENABLE);                        // power enable pin as output
  pinDisable(PIN_KEYS);                         // disable digital input buffer
  MIL_init();                                   // init millis counter
  ADC_init();                                   // init ADC
  INA_init();                                   // init INA219
  OLED_init();                                  // init OLED
  OLED_clearScreen();                           // clear screen
  EEPROM_get();                                 // read user settings from EEPROM
  lastmillis = MIL_read();                      // read millis counter

  // Loop
  while(1) {
    // Read sensor values
    voltage = INA_readVoltage();                // read voltage in mV from INA219
    current = INA_readCurrent();                // read current in mA from INA219  

    // Calculate timings
    nowmillis   = MIL_read();                   // read millis counter
    interval    = nowmillis - lastmillis;       // calculate recent time interval
    lastmillis  = nowmillis;                    // reset lastmillis
    if(isCharging) chargetime += interval;      // calculate charging time
    seconds     = chargetime / 1000;            // calculate total seconds
    if(seconds > 35999) seconds = 35999;        // limit seconds timer
    minutes     = seconds / 60;                 // calculate total minutes

    // Calculate power, capacity and energy
    power = (uint32_t)voltage * current / 1000; // calculate power    in mW
    capacity += interval * current / 3600;      // calculate capacity in uAh
    energy   += interval * power   / 3600;      // calculate energy   in uWh

    // Check if charging limit is reached
    if(isCharging) {
      switch(limit) {
        case 0:   if((capacity / 1000) >= limit_val[0]) isCharging = 0; break;
        case 1:   if((energy   / 1000) >= limit_val[1]) isCharging = 0; break;
        case 2:   if(current < limit_val[2]) {
                    if(nowmillis > limitmillis) isCharging = 0;
                  }
                  else limitmillis = nowmillis + 5000;
                  break;
        case 3:   if(minutes >= limit_val[3]) isCharging = 0; break;
        default:  break;
      }
      if(!isCharging) pinLow(PIN_ENABLE);
    }

    // Check button and take proper action
    button = readButton();
    switch(button) {
      case KEY_SELECT:  if(button != lastbutton) {
                          if(isCharging) showValue++;
                          else limit++;
                          if(limit > 3) limit = 0;
                          if(showValue > 2) showValue = 0;
                        }
                        break;
      case KEY_INC:     if(!isCharging) {
                          if(limit_val[limit] <  pgm_read_word(&limit_max[limit]))
                             limit_val[limit] += pgm_read_word(&limit_inc[limit]);
                        }
                        break;
      case KEY_DEC:     if(!isCharging) {
                          if(limit_val[limit]  > pgm_read_word(&limit_min[limit]))
                             limit_val[limit] -= pgm_read_word(&limit_inc[limit]);
                        }
                        break;
      case KEY_START:   if(button != lastbutton) {
                          isCharging = !isCharging;
                          isCharging ? pinHigh(PIN_ENABLE) : pinLow(PIN_ENABLE);
                          EEPROM_update();
                          limitmillis = nowmillis + 5000;
                        }
                        break;
      default:          break;
    }
    lastbutton = button;

    // Update OLED
    OLED_setCursor(0, 0);
    OLED_printPrg(limitStr);
    OLED_printDec16(limit_val[limit]);
    OLED_printPrg(limit_s + (limit << 2));

    OLED_setCursor(92, 0);
    if(isCharging) OLED_printPrg(chargeStr);
    else           OLED_printPrg(pauseStr);

    OLED_setCursor(0, 2);
    if(showValue) {
      OLED_printChar(minutes / 60); OLED_printChar(COLON);
      OLED_printDec8(minutes % 60); OLED_printChar(COLON);
      OLED_printDec8(seconds % 60); OLED_printChar(SPACE);
    }

    switch(showValue) {
      case 0:   OLED_printDec16(voltage);
                OLED_printPrg(voltStr);
                OLED_printDec16(current);
                OLED_printPrg(currStr);
                break;
      case 1:   OLED_printDec16(capacity / 1000);
                OLED_printPrg(limit_s);
                break;
      case 2:   OLED_printDec16(energy / 1000);
                OLED_printPrg(limit_s + 4);
                break;
      default:  break;
    }

    // A little delay
    _delay_ms(125);
  }
}
